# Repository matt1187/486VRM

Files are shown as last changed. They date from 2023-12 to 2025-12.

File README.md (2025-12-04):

# Project  486VRM.
A interposer for  3.3V 486  for using on motherboard without 3.3V regulator.
A advantage of this  486VRM interposer: switching regulator instead linear regulator. -> less heating.

# PCB Revision History
- 000 initial draft
- 001 smaller pcb size, current limit resistor added for Intel DX4 I/O buffer (pin J1), added solder help

# Feartures
- Vcore can be adjusting with jumper: 3.3V,  3.45 and 4V
- Clock-Multi jumper (for some DX4 and AMD/Cyrix 5x86)
- Writeback L1 jumper 
- connector for fan, 5V
  
grafik

# Pictures & how to soldering of pin
- I use "BGA"-technologie on this interposer.
grafikgrafik
- using of solder paste is very recommend.
- you need solder iron with long and small chisel for extra adding of tin to socket.

grafik

- "solder helper hold pin (bottom) on their place.
- very recommend: solder only one row with pin to pcb, then second row, then third row.

# Bill of material
[Gerber data 001

|Footprint|Count|Value|Supplier|Order-number|
|---|----|-----|---|---|
|Top1|1|486|various|PGA-168 486 168pin socket|
|Bot1|1|486|various| turned pin header, dia =0.5mm|
|JP1|1|WB/WT|Digikey|609-78511-203HLF-ND|
|JP2|1|voltage|Digikey|609-78511-203HLF-ND|
|JP3|1|CLKMUL|Digikey|609-78511-203HLF-ND|
|JP4|1|FAN|Digikey|609-78511-203HLF-ND|
|U1|1|TPS54308DDCR|Digikey|296-47880-1-ND|
|R1|1|50Ω|Digikey|541-CRCW080550R0FKTACT-ND |
|R2|1|100kΩ|Digikey|311-100KARCT-ND |
|R3|1|22kΩ|Digikey|311-22KARCT-ND|
|R4|1|430kΩ|Digikey|311-430KARCT-ND |
|R5|1|91kΩ|Digikey|311-91KARCT-ND |
|R6|1|100Ω|Digikey|603-RC0805JR-07100RL|
|C4,C3,C2,C1|4|10µF|Digikey|399-C1206C106M3PAC7210CT-ND |
|C6|1|75pf|Digikey|478-3743-1-ND|
|C10,C9,C8,C7,C5|5|0.1µF|Digikey|KGM21NR71H104KT|
|C11|1|47µF|Digikey|T491C476M010AT|
|L1|1|10µh|Digikey|LMLP07A7M100DTAS |

# License
The project is free for non-commercial reproduction. Do not sell it on Ebay or other platforms for profit. Do not make a closed source derivative. Share your experiences and ideas with the community.

This work is licensed under a [Creative Commons Attribution-NonCommercial-ShareAlike 4.0 International License][cc-by-nc-sa].

[][cc-by-nc-sa]

[cc-by-nc-sa]: http://creativecommons.org/licenses/by-nc-sa/4.0/
[cc-by-nc-sa-image]: https://licensebuttons.net/l/by-nc-sa/4.0/88x31.png

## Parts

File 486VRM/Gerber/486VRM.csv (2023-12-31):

ID | Footprint | Case | Count | Value | Supplier; order-number
1 | R6 | R_0805_2012Metric | 1 | 100 | Mouser | 603-RC0402JR-07100RL
2 | Top1 | PGA-168_socket | 1 | 486 | various | PGA-168 486 168pin socket
3 | C11 | CP_EIA-6032-15_Kemet-U | 1 | 47µ | Mouser | 80-T491C476M010
4 | C10,C9,C8,C7,C5 | C_0805_2012Metric | 5 | 0.1µF | Mouser | 581-08055C104K
5 | Bot1 | PGA-168_pin | 1 | 486 | various | turned pin header, dia =0.5mm
6 | JP4 | PinHeader_1x03_P2.54mm_Vertical | 1 | FAN | Mouser | 649-78511-203HLF
7 | JP2 | PinHeader_1x03_P2.54mm_Vertical | 1 | voltage | Mouser | 649-78511-203HLF
8 | JP1 | PinHeader_1x03_P2.54mm_Vertical | 1 | WB/WT | Mouser | 649-78511-203HLF
9 | JP3 | PinHeader_1x03_P2.54mm_Vertical | 1 | CLKMUL | Mouser | 649-78511-203HLF
10 | U1 | SOT-23-6 | 1 | TPS54308DDCR | Mouser | 595-TPS54308DDCR
11 | R5 | R_0805_2012Metric | 1 | 91k | Mouser | 603-RC0805JR-0791KL
12 | R4 | R_0805_2012Metric | 1 | 430k | Mouser | 603-RC0805JR-07430KL
13 | R3 | R_0805_2012Metric | 1 | 22k | Mouser | 603-RC0805JR-0722KL
14 | R2 | R_0805_2012Metric | 1 | 100k | Mouser | 603-RC0805JR-07100KL
15 | R1 | R_0805_2012Metric | 1 | 50 | Mouser | 603-RC0402JR-0750RL
16 | L1 | L_Taiyo-Yuden_NR-80xx | 1 | 10µh | Mouser | 581-LMLP07A7M100DTAS
17 | C6 | C_0805_2012Metric | 1 | 75pf | Mouser | 581-08051A750J
18 | C4,C3,C2,C1 | C_1206_3216Metric | 4 | 10µF | Mouser | 80-C1206C106M3P

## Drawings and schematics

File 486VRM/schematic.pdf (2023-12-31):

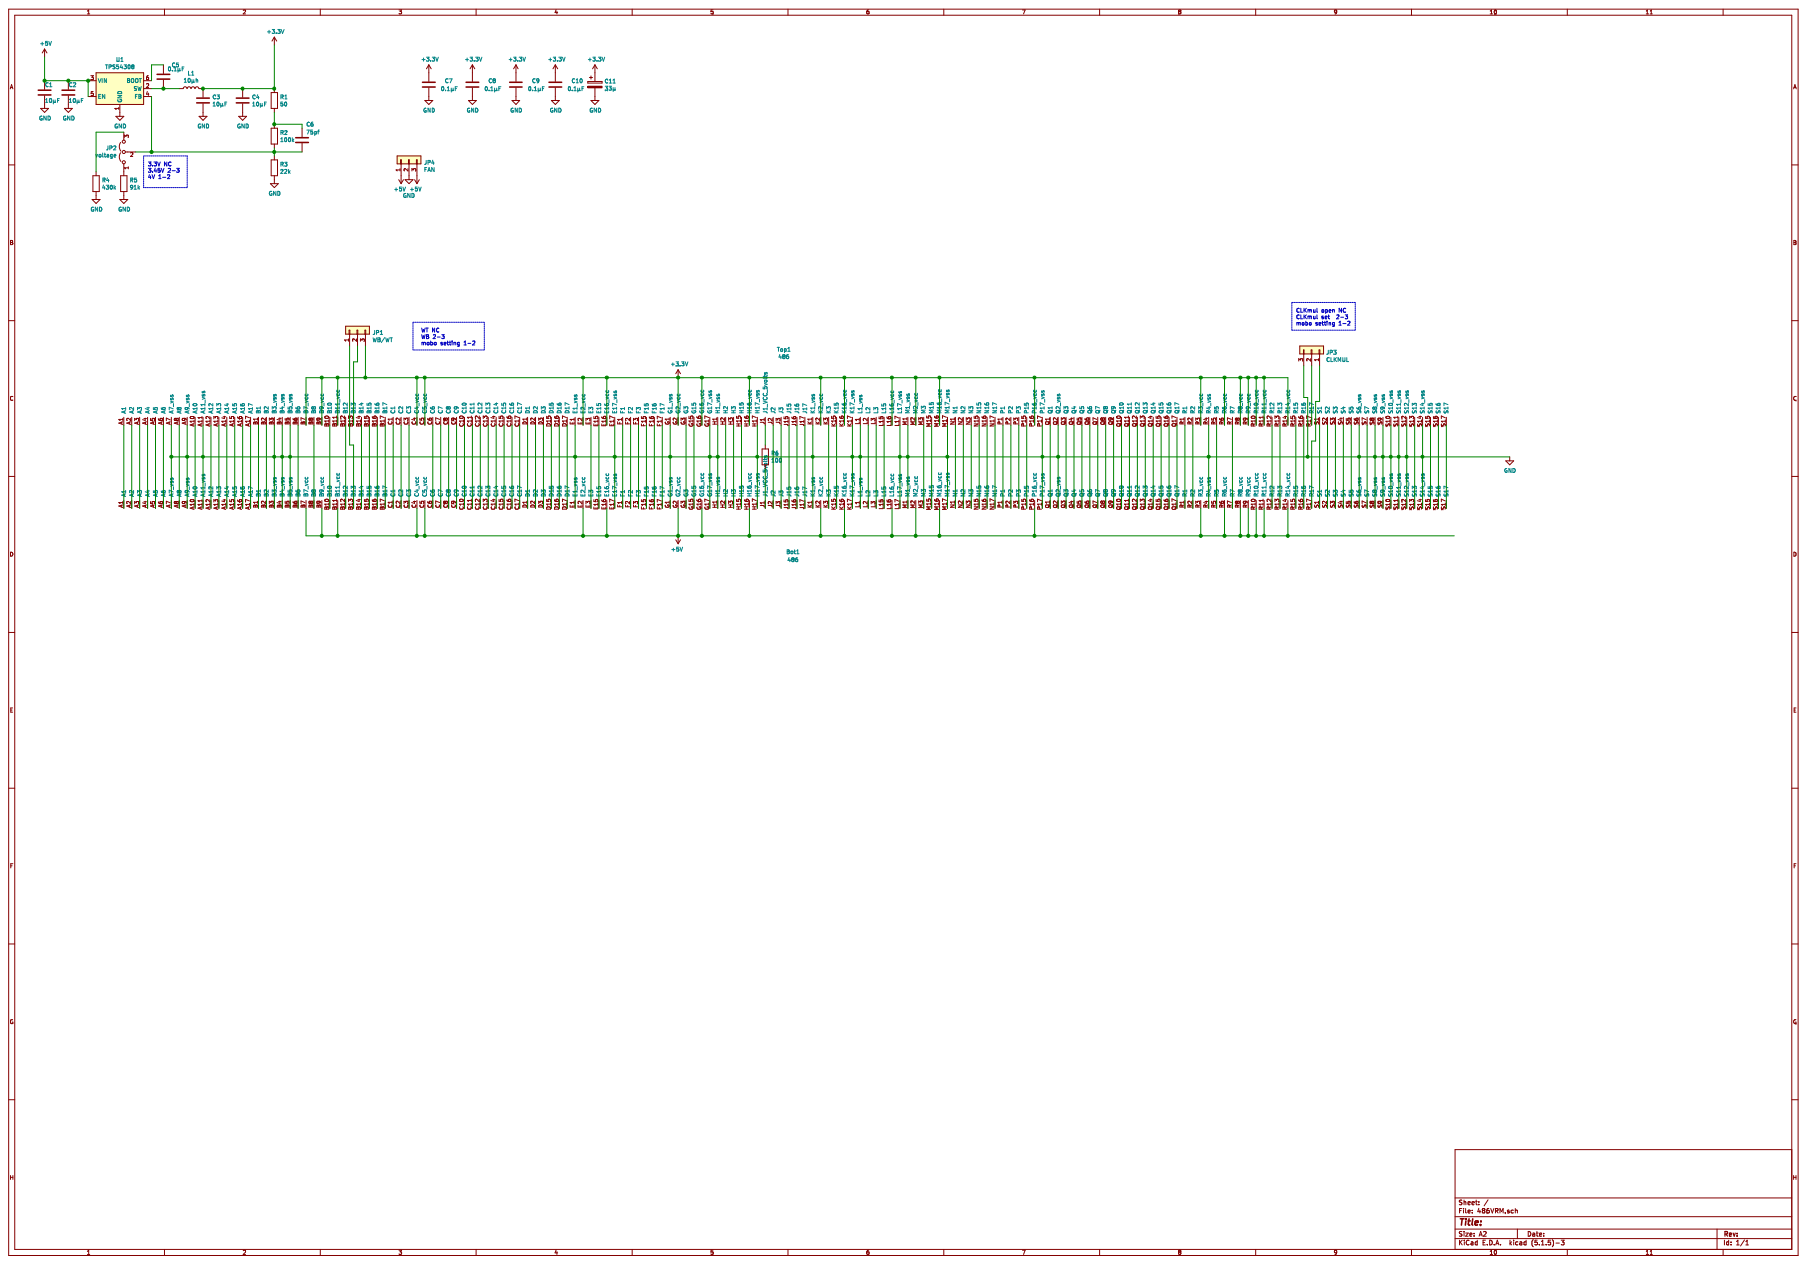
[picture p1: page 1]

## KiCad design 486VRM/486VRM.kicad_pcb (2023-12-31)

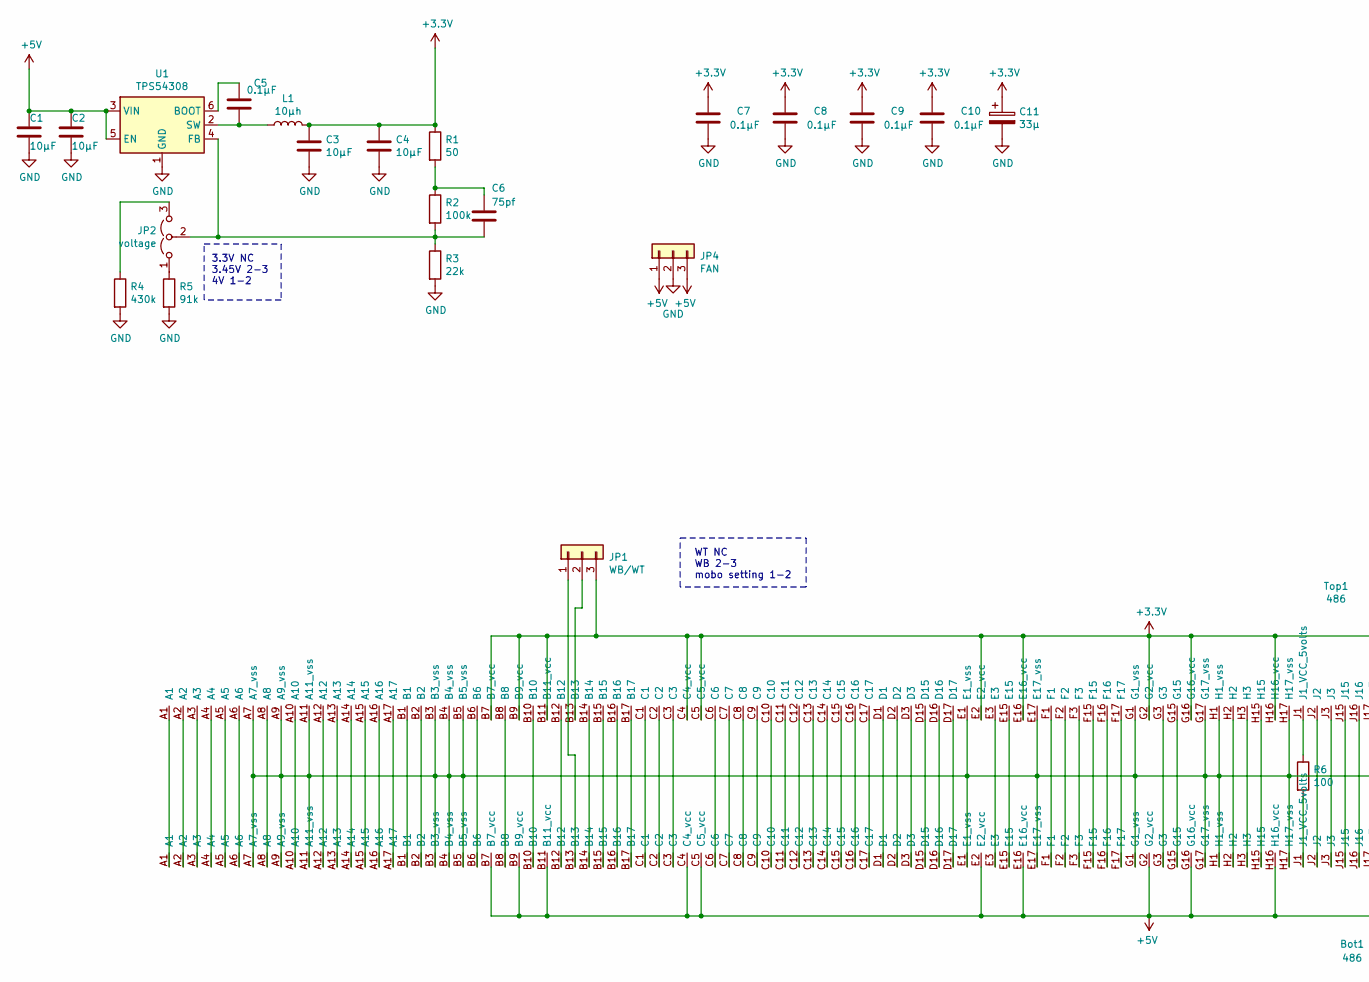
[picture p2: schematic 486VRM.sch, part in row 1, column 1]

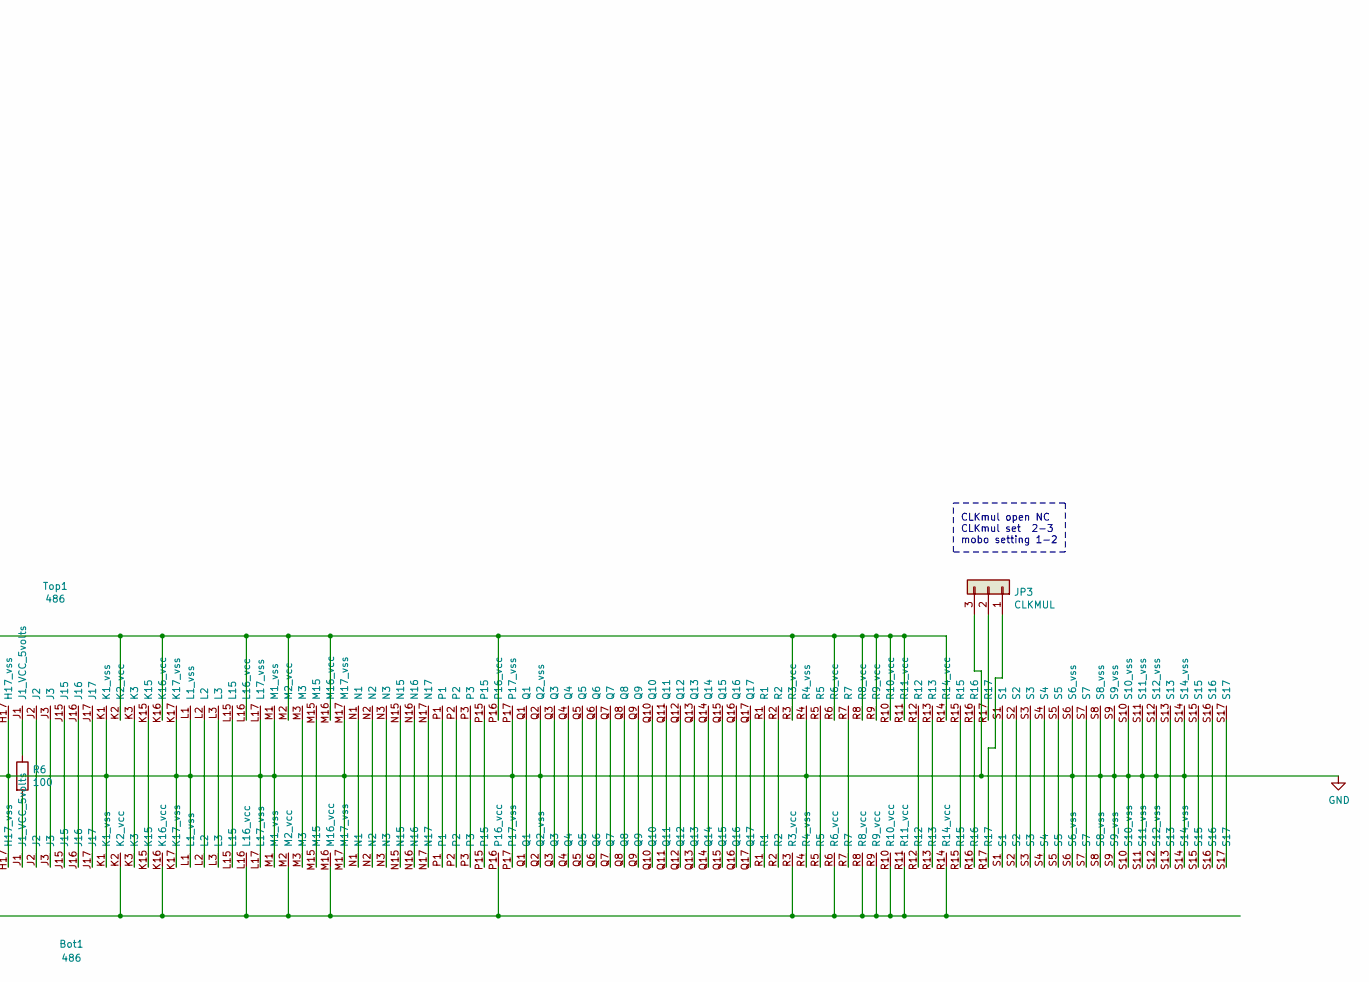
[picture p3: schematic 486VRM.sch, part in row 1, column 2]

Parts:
Bot1: 486; PGA-168_Socket
C1, C2, C3, C4: 10µF; C_1206_3216Metric
C5, C7, C8, C9, C10: 0.1µF; C_0805_2012Metric
C6: 75pf; C_0805_2012Metric
C11: 33µ; CP_EIA-6032-15_Kemet-U
JP1: WB/WT; PinHeader_1x03_P2.54mm_Vertical
JP2: voltage; PinHeader_1x03_P2.54mm_Vertical
JP3: CLKMUL; PinHeader_1x03_P2.54mm_Vertical
JP4: FAN; PinHeader_1x03_P2.54mm_Vertical
L1: 10µh; L_Taiyo-Yuden_NR-80xx
R1: 50; R_0805_2012Metric
R2: 100k; R_0805_2012Metric
R3: 22k; R_0805_2012Metric
R4: 430k; R_0805_2012Metric
R5: 91k; R_0805_2012Metric
R6: 100; R_0805_2012Metric
Top1: 486; PGA-168
U1: TPS54308; SOT-23-6

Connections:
+3V3: C3.1, C4.1, C7.1, C8.1, C9.1, C10.1, C11.1, JP1.3, L1.2, R1.1, Top1.B7 (B7_vcc), Top1.B9 (B9_vcc), Top1.B11 (B11_vcc), Top1.C4 (C4_vcc), Top1.C5 (C5_vcc), Top1.E2 (E2_vcc), Top1.E16 (E16_vcc), Top1.G2 (G2_vcc), Top1.G16 (G16_vcc), Top1.H16 (H16_vcc), Top1.K2 (K2_vcc), Top1.K16 (K16_vcc), Top1.L16 (L16_vcc), Top1.M2 (M2_vcc), Top1.M16 (M16_vcc), Top1.P16 (P16_vcc), Top1.R3 (R3_vcc), Top1.R6 (R6_vcc), Top1.R8 (R8_vcc), Top1.R9 (R9_vcc), Top1.R10 (R10_vcc), Top1.R11 (R11_vcc), Top1.R14 (R14_vcc)
+5V: Bot1.B7 (B7_vcc), Bot1.B9 (B9_vcc), Bot1.B11 (B11_vcc), Bot1.C4 (C4_vcc), Bot1.C5 (C5_vcc), Bot1.E2 (E2_vcc), Bot1.E16 (E16_vcc), Bot1.G2 (G2_vcc), Bot1.G16 (G16_vcc), Bot1.H16 (H16_vcc), Bot1.K2 (K2_vcc), Bot1.K16 (K16_vcc), Bot1.L16 (L16_vcc), Bot1.M2 (M2_vcc), Bot1.M16 (M16_vcc), Bot1.P16 (P16_vcc), Bot1.R3 (R3_vcc), Bot1.R6 (R6_vcc), Bot1.R8 (R8_vcc), Bot1.R9 (R9_vcc), Bot1.R10 (R10_vcc), Bot1.R11 (R11_vcc), Bot1.R14 (R14_vcc), C1.1, C2.1, JP4.1, JP4.3, U1.3 (VIN), U1.5 (EN)
GND: Bot1.A7 (A7_vss), Bot1.A9 (A9_vss), Bot1.A11 (A11_vss), Bot1.B3 (B3_vss), Bot1.B4 (B4_vss), Bot1.B5 (B5_vss), Bot1.E1 (E1_vss), Bot1.E17 (E17_vss), Bot1.G1 (G1_vss), Bot1.G17 (G17_vss), Bot1.H1 (H1_vss), Bot1.H17 (H17_vss), Bot1.K1 (K1_vss), Bot1.K17 (K17_vss), Bot1.L1 (L1_vss), Bot1.L17 (L17_vss), Bot1.M1 (M1_vss), Bot1.M17 (M17_vss), Bot1.P17 (P17_vss), Bot1.Q2 (Q2_vss), Bot1.R4 (R4_vss), Bot1.S6 (S6_vss), Bot1.S8 (S8_vss), Bot1.S9 (S9_vss), Bot1.S10 (S10_vss), Bot1.S11 (S11_vss), Bot1.S12 (S12_vss), Bot1.S14 (S14_vss), C1.2, C2.2, C3.2, C4.2, C7.2, C8.2, C9.2, C10.2, C11.2, JP3.3, JP4.2, R3.2, R4.2, R5.2, Top1.A7 (A7_vss), Top1.A9 (A9_vss), Top1.A11 (A11_vss), Top1.B3 (B3_vss), Top1.B4 (B4_vss), Top1.B5 (B5_vss), Top1.E1 (E1_vss), Top1.E17 (E17_vss), Top1.G1 (G1_vss), Top1.G17 (G17_vss), Top1.H1 (H1_vss), Top1.H17 (H17_vss), Top1.K1 (K1_vss), Top1.K17 (K17_vss), Top1.L1 (L1_vss), Top1.L17 (L17_vss), Top1.M1 (M1_vss), Top1.M17 (M17_vss), Top1.P17 (P17_vss), Top1.Q2 (Q2_vss), Top1.R4 (R4_vss), Top1.S6 (S6_vss), Top1.S8 (S8_vss), Top1.S9 (S9_vss), Top1.S10 (S10_vss), Top1.S11 (S11_vss), Top1.S12 (S12_vss), Top1.S14 (S14_vss), U1.1 (GND)
unnamed: Bot1.A1, Top1.A1
unnamed: Bot1.A2, Top1.A2
unnamed: Bot1.A3, Top1.A3
unnamed: Bot1.A4, Top1.A4
unnamed: Bot1.A5, Top1.A5
unnamed: Bot1.A6, Top1.A6
unnamed: Bot1.A8, Top1.A8
unnamed: Bot1.A10, Top1.A10
unnamed: Bot1.A12, Top1.A12
unnamed: Bot1.A13, Top1.A13
unnamed: Bot1.A14, Top1.A14
unnamed: Bot1.A15, Top1.A15
unnamed: Bot1.A16, Top1.A16
unnamed: Bot1.A17, Top1.A17
unnamed: Bot1.B1, Top1.B1
unnamed: Bot1.B2, Top1.B2
unnamed: Bot1.B6, Top1.B6
unnamed: Bot1.B8, Top1.B8
unnamed: Bot1.B10, Top1.B10
unnamed: Bot1.B12, Top1.B12
unnamed: Bot1.B13, JP1.1
unnamed: Bot1.B14, Top1.B14
unnamed: Bot1.B15, Top1.B15
unnamed: Bot1.B16, Top1.B16
unnamed: Bot1.B17, Top1.B17
unnamed: Bot1.C1, Top1.C1
unnamed: Bot1.C2, Top1.C2
unnamed: Bot1.C3, Top1.C3
unnamed: Bot1.C6, Top1.C6
unnamed: Bot1.C7, Top1.C7
unnamed: Bot1.C8, Top1.C8
unnamed: Bot1.C9, Top1.C9
unnamed: Bot1.C10, Top1.C10
unnamed: Bot1.C11, Top1.C11
unnamed: Bot1.C12, Top1.C12
unnamed: Bot1.C13, Top1.C13
unnamed: Bot1.C14, Top1.C14
unnamed: Bot1.C15, Top1.C15
unnamed: Bot1.C16, Top1.C16
unnamed: Bot1.C17, Top1.C17
unnamed: Bot1.D1, Top1.D1
unnamed: Bot1.D2, Top1.D2
unnamed: Bot1.D3, Top1.D3
unnamed: Bot1.D15, Top1.D15
unnamed: Bot1.D16, Top1.D16
unnamed: Bot1.D17, Top1.D17
unnamed: Bot1.E3, Top1.E3
unnamed: Bot1.E15, Top1.E15
unnamed: Bot1.F1, Top1.F1
unnamed: Bot1.F2, Top1.F2
unnamed: Bot1.F3, Top1.F3
unnamed: Bot1.F15, Top1.F15
unnamed: Bot1.F16, Top1.F16
unnamed: Bot1.F17, Top1.F17
unnamed: Bot1.G3, Top1.G3
unnamed: Bot1.G15, Top1.G15
unnamed: Bot1.H2, Top1.H2
unnamed: Bot1.H3, Top1.H3
unnamed: Bot1.H15, Top1.H15
unnamed: Bot1.J1 (J1_VCC_5volts), R6.2
unnamed: Bot1.J2, Top1.J2
unnamed: Bot1.J3, Top1.J3
unnamed: Bot1.J15, Top1.J15
unnamed: Bot1.J16, Top1.J16
unnamed: Bot1.J17, Top1.J17
unnamed: Bot1.K3, Top1.K3
unnamed: Bot1.K15, Top1.K15
unnamed: Bot1.L2, Top1.L2
unnamed: Bot1.L3, Top1.L3
unnamed: Bot1.L15, Top1.L15
unnamed: Bot1.M3, Top1.M3
unnamed: Bot1.M15, Top1.M15
unnamed: Bot1.N1, Top1.N1
unnamed: Bot1.N2, Top1.N2
unnamed: Bot1.N3, Top1.N3
unnamed: Bot1.N15, Top1.N15
unnamed: Bot1.N16, Top1.N16
unnamed: Bot1.N17, Top1.N17
unnamed: Bot1.P1, Top1.P1
unnamed: Bot1.P2, Top1.P2
unnamed: Bot1.P3, Top1.P3
unnamed: Bot1.P15, Top1.P15
unnamed: Bot1.Q1, Top1.Q1
unnamed: Bot1.Q3, Top1.Q3
unnamed: Bot1.Q4, Top1.Q4
unnamed: Bot1.Q5, Top1.Q5
unnamed: Bot1.Q6, Top1.Q6
unnamed: Bot1.Q7, Top1.Q7
unnamed: Bot1.Q8, Top1.Q8
unnamed: Bot1.Q9, Top1.Q9
unnamed: Bot1.Q10, Top1.Q10
unnamed: Bot1.Q11, Top1.Q11
unnamed: Bot1.Q12, Top1.Q12
unnamed: Bot1.Q13, Top1.Q13
unnamed: Bot1.Q14, Top1.Q14
unnamed: Bot1.Q15, Top1.Q15
unnamed: Bot1.Q16, Top1.Q16
unnamed: Bot1.Q17, Top1.Q17
unnamed: Bot1.R1, Top1.R1
unnamed: Bot1.R2, Top1.R2
unnamed: Bot1.R5, Top1.R5
unnamed: Bot1.R7, Top1.R7
unnamed: Bot1.R12, Top1.R12
unnamed: Bot1.R13, Top1.R13
unnamed: Bot1.R15, Top1.R15
unnamed: Bot1.R16, Top1.R16
unnamed: Bot1.R17, JP3.1
unnamed: Bot1.S1, Top1.S1
unnamed: Bot1.S2, Top1.S2
unnamed: Bot1.S3, Top1.S3
unnamed: Bot1.S4, Top1.S4
unnamed: Bot1.S5, Top1.S5
unnamed: Bot1.S7, Top1.S7
unnamed: Bot1.S13, Top1.S13
unnamed: Bot1.S15, Top1.S15
unnamed: Bot1.S16, Top1.S16
unnamed: Bot1.S17, Top1.S17
unnamed: C5.1, U1.6 (BOOT)
unnamed: C5.2, L1.1, U1.2 (SW)
unnamed: C6.1, R1.2, R2.1
unnamed: C6.2, JP2.2 (C), R2.2, R3.1, U1.4 (FB)
unnamed: JP1.2, Top1.B13
unnamed: JP2.1 (A), R5.1
unnamed: JP2.3 (B), R4.1
unnamed: JP3.2, Top1.R17
unnamed: R6.1, Top1.J1 (J1_VCC_5volts)

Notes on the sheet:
3.3V NC 3.45V 2-3 4V 1-2
WT NC WB 2-3 mobo setting 1-2
CLKmul open NC CLKmul set 2-3 mobo setting 1-2

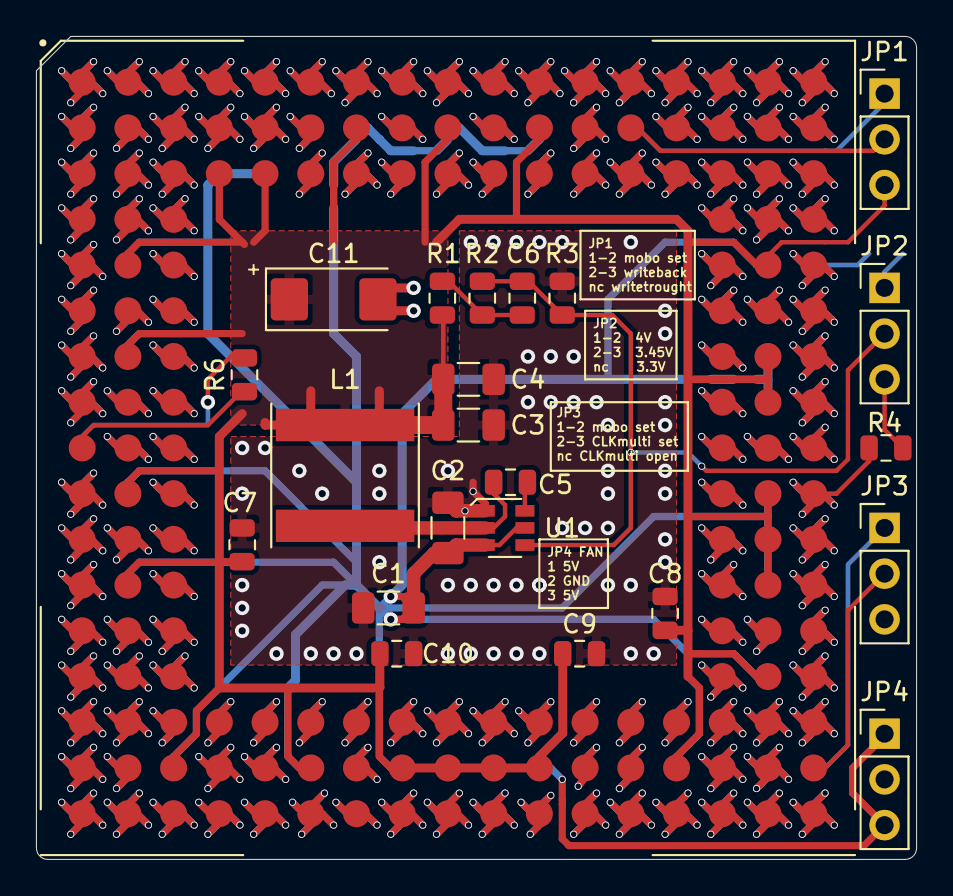
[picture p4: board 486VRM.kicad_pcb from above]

Board: 2 copper layers, 48.9 x 45.7 mm, 25 parts (1 on the bottom side), 129 nets.
